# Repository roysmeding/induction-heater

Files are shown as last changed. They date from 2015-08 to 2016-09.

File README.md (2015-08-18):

# Induction heater design files

## Disclaimer
WARNING: THIS DESIGN IS UNTESTED. ADDITIONALLY, IF YOU ATTEMPT TO BUILD ONE
OF THESE WITHOUT FULLY UNDERSTANDING WHAT YOU'RE DOING, YOU WILL PROBABLY DIE.
DON'T SAY I DIDN'T WARN YOU!

## Introduction
Now that that's out of the way: this repository contains the design files for
an induction heater meant to heat metals to forging or melting temperature.

Rough specs:

- 3.5kW design power (just right for a standard 230V circuit in the Netherlands)
- Water-cooled work coil so we can heat fairly conductive metal like aluminium
- Main power stage uses salvaged parts from an induction cooktop.
- Microcontroller-based control system

This project is still very much a work in progress, but some preliminary design
files are available, as well as simulation work.

## License
This work is licensed under the Creative Commons Attribution 4.0 International
License. To view a copy of this license, visit http://creativecommons.org/licenses/by/4.0/.

## Contact
Your best bet is to contact the primary suspect (Roy Smeding; roy.smeding@gmail.com)
for more information.

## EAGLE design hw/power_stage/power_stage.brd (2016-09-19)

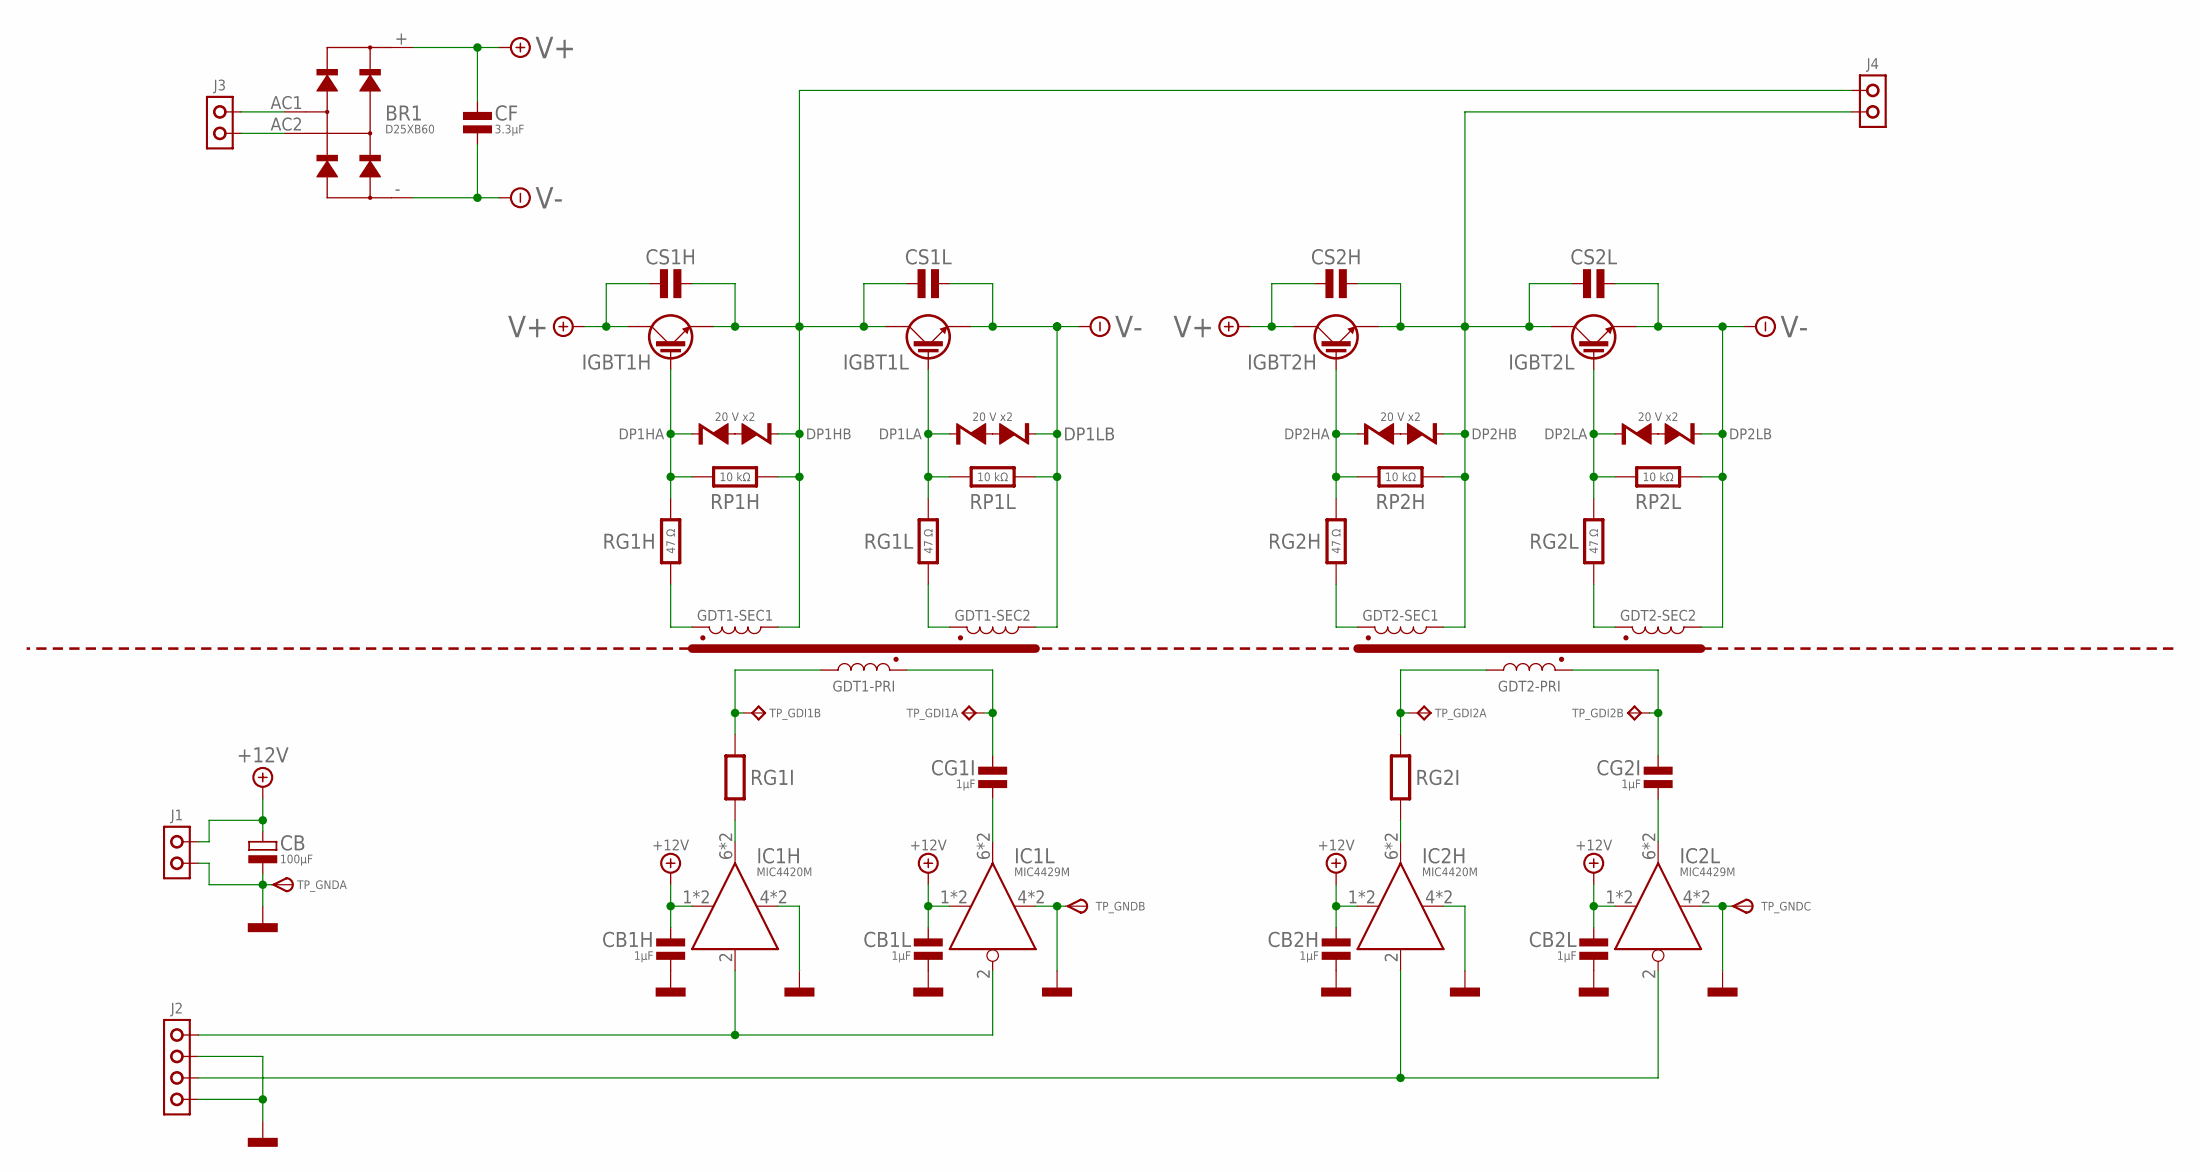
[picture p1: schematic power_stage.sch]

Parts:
BR1: D25XB60
CB: 100µF; CPOL-PANASONIC-B
CB1H, CB1L, CB2H, CB2L: 1µF; C-0805
CF: 3.3µF; C-R75
CG1I, CG2I: 1µF; C-0805
CS1H, CS1L, CS2H, CS2L: C_R76; C-R76
DP1HA, DP1HB, DP1LA, DP1LB, DP2HA, DP2HB, DP2LA, DP2LB: 20 V; SOD80C
GDT1, GDT2: GDT
IC1H, IC2H: MIC4420M; SO-08
IC1L, IC2L: MIC4429M; SO-08
IGBT1H, IGBT1L, IGBT2H, IGBT2L: IXGR32N60CD1; TO-247AD-V
J1: CON-2POS-NS25
J2: CON-4POS-NS25
J3, J4: CON-2POS-MNL; TE-350824-1
RG1H, RG1L, RG2H, RG2L: 47 Ω; R-0805
RG1I, RG2I: R-0805
RP1H, RP1L, RP2H, RP2L: 10 kΩ; R-0805
TP_GDI1A, TP_GDI2B: A; TP10SQ
TP_GDI1B, TP_GDI2A: B; TP10SQ
TP_GNDA: GND; P1-13
TP_GNDB: GND; P1-13
TP_GNDC: GND; P1-13

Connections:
+12V: CB.+, CB1H.1, CB1L.1, CB2H.1, CB2L.1, IC1H.1 (VS), IC1H.8 (VS), IC1L.1 (VS), IC1L.8 (VS), IC2H.1 (VS), IC2H.8 (VS), IC2L.1 (VS), IC2L.8 (VS), J1.1
AC1: BR1.AC1, J3.1
AC2: BR1.AC2, J3.2
GND: CB.-, CB1H.2, CB1L.2, CB2H.2, CB2L.2, IC1H.4 (GND), IC1H.5 (GND), IC1L.4 (GND), IC1L.5 (GND), IC2H.4 (GND), IC2H.5 (GND), IC2L.4 (GND), IC2L.5 (GND), J1.2, J2.2, J2.4, TP_GNDA.TP, TP_GNDB.TP, TP_GNDC.TP
unnamed: GDT1.PRI-2 (2), RG1I.2, TP_GDI1B.TP
unnamed: IC1H.6 (OUT), IC1H.7 (OUT), RG1I.1
unnamed: GDT1.SEC1-1 (1), RG1H.1
unnamed: IC2H.6 (OUT), IC2H.7 (OUT), RG2I.1
unnamed: GDT2.PRI-2 (2), RG2I.2, TP_GDI2A.TP
unnamed: DP1LA.C, IGBT1L.G, RG1L.2, RP1L.2
unnamed: GDT1.SEC2-1 (1), RG1L.1
unnamed: DP2LA.C, IGBT2L.G, RG2L.2, RP2L.2
unnamed: DP1HA.C, IGBT1H.G, RG1H.2, RP1H.2
unnamed: GDT2.SEC2-1 (1), RG2L.1
unnamed: GDT2.SEC1-1 (1), RG2H.1
unnamed: DP2HA.C, IGBT2H.G, RG2H.2, RP2H.2
unnamed: IC1H.2 (IN), IC1L.2 (IN), J2.1
unnamed: DP1LA.A, DP1LB.A
unnamed: DP1HA.A, DP1HB.A
unnamed: IC2H.2 (IN), IC2L.2 (IN), J2.3
unnamed: CG1I.2, IC1L.6 (OUT), IC1L.7 (OUT)
unnamed: DP2HA.A, DP2HB.A
unnamed: DP2LA.A, DP2LB.A
unnamed: CG2I.2, IC2L.6 (OUT), IC2L.7 (OUT)
unnamed: CG1I.1, GDT1.PRI-1 (1), TP_GDI1A.TP
unnamed: CG2I.1, GDT2.PRI-1 (1), TP_GDI2B.TP
OUT1: CS1H.P$1, CS1L.P$2, DP1HB.C, GDT1.SEC1-2 (2), IGBT1H.S (E), IGBT1L.D (C), J4.1, RP1H.1
OUT2: CS2H.P$1, CS2L.P$2, DP2HB.C, GDT2.SEC1-2 (2), IGBT2H.S (E), IGBT2L.D (C), J4.2, RP2H.1
V+: BR1.+, CF.P$2, CS1H.P$2, CS2H.P$2, IGBT1H.D (C), IGBT2H.D (C)
V-: BR1.-, CF.P$1, CS1L.P$1, CS2L.P$1, DP1LB.C, DP2LB.C, GDT1.SEC2-2 (2), GDT2.SEC2-2 (2), IGBT1L.S (E), IGBT2L.S (E), RP1L.1, RP2L.1

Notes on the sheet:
20 V x2

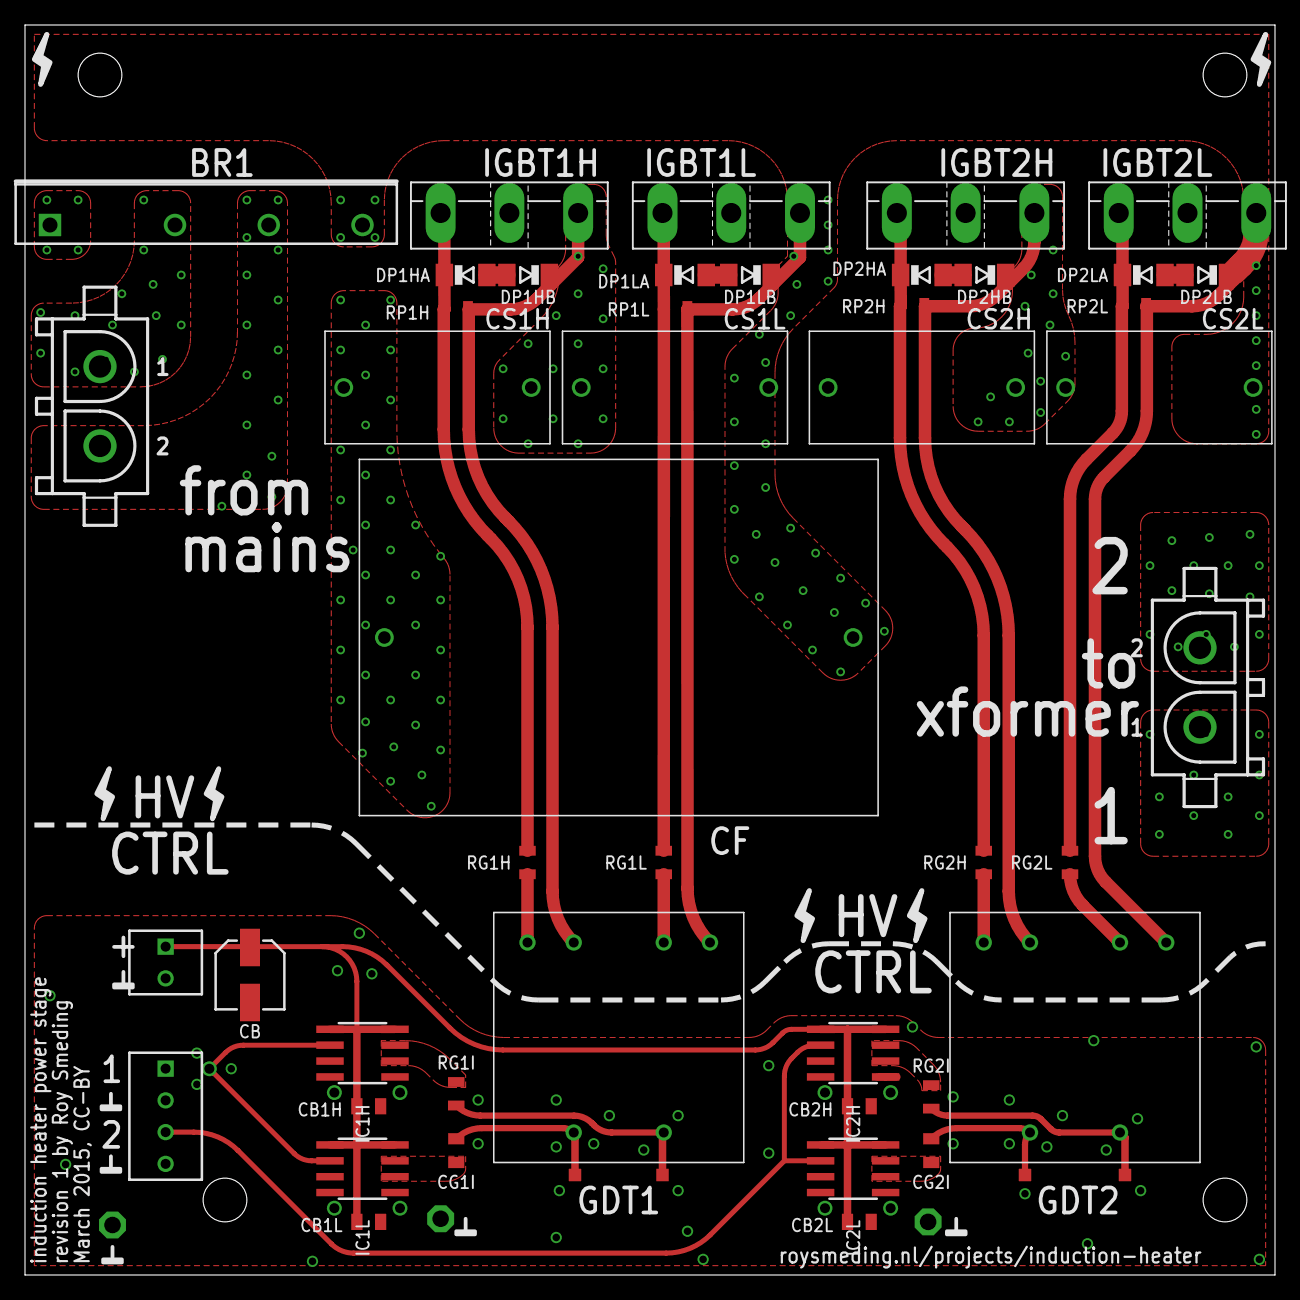
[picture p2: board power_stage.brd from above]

Board: 2 copper layers, 100.0 x 100.0 mm, 52 parts (0 on the bottom side), 30 nets.

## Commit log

2015-03-06 Initial commit; basic untested design is here
    [power_stage.brd, power_stage.sch, system.sch]
2015-03-09 Adapted power_stage.brd to be 100x100mm
    This enables us to use cheap PCB fab services.
    [power_stage.brd, power_stage.sch]
2015-03-09 More cleanup
    [system.sch]
2015-03-12 Remove solder mask from high current tracks so we can cheaply increase their current capacity
    [power_stage.brd, power_stage.sch]
2015-03-13 More fiddling
    [power_stage.brd, power_stage.sch]
2015-03-16 Add URL to board
    [power_stage.brd]
2015-03-16 Fix unconnected output pin on gate driver ICs
    [power_stage.brd, power_stage.sch]
2015-03-19 why not
    [power_stage.brd]
2015-03-19 Move some vias
    [power_stage.brd]
2015-03-20 REVISION ONE!
    [power_stage.brd]
2015-08-18 Power stage: fix incorrect GDT footprint
    Turns out I must've measured wrong when i determined the polarity of the
    GDT windings, but one of the secondary windings has the opposite
    polarity to what I had in the layout. Makes sense, since this does make
    the layout somewhat more direct.
    Doesn't matter much now since my boards have already been produced (I'll
    be patching them by hand) and it's unlikely anyone will end up using the
    same GDTs, but just in case, I figured I'd make it easier on myself when
    referring to the design files.
    [power_stage.brd, power_stage.sch]
2016-09-18 Added STM32F334 (microcontroller) to library, newer EAGLE project version
2016-09-18 Clean up the power stage schematic
    This means the board changed a bit too
    [power_stage.brd, power_stage.sch]
2016-09-19 Changed power stage PCB connectors
    [power_stage.brd, power_stage.sch]

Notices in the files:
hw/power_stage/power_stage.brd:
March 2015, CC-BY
